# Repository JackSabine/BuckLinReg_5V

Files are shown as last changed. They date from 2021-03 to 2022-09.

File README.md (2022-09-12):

# Buck + Linear Regulator

Power supply for the Breadboard\_CPU.  This converter accepts input voltages 8 - 13 V and will output a regulated 5 V.

Finished PCB of the power supply

Tried to bodge a wire to measure a voltage without a testpoint...  Oops...

Oops

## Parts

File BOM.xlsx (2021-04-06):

MFPN | Digikey PN | Qty
156120RS75000 | 732-5030-1-ND | 2
156120VS75000 | 732-5032-1-ND | 2
156120YS75000 | 732-5034-1-ND | 2
796634-4 | A98225-ND | 2
796638-4 | A98237-ND | 2
A750EK476M1EAAE040 | 399-13665-ND | 2
BZX84C10-7-F | BZX84C10-FDICT-ND | 2
BZX84-C2V4,215 | 1727-4249-1-ND‎ (https://www.digikey.com/product-detail/en/BZX84-C2V4%2c215/1727-4249-1-ND/2122205/?itemSeq=360465044) | 2
C3216X7R1H106K160AC | 445-181601-1-ND | 4
‎CL32B106KBJNNWE‎ | 1276-3388-1-ND‎ (https://www.digikey.com/product-detail/en/CL32B106KBJNNWE/1276-3388-1-ND/3891474) | 4
CSR1206FT10L0 | CSR1206FT10L0CT-ND | 2
EG1201 | EG1901-ND | 2
GCM21BR72A104KA37L | 490-4789-1-ND | 4
GRM188R72A104KA35D | 490-3285-1-ND | 16
IHLP4040DZER6R8M8A | 541-2276-1-ND | 2
INA180A3IDBVR | 296-47654-1-ND‎ (https://www.digikey.com/product-detail/en/INA180A3IDBVR/296-47654-1-ND/8133023/?itemSeq=360296412) | 2
LM1085ISX-5.0/NOPB | 296-35391-1-ND | 2
PMBT2222 | 1727-1135-1-ND | 2
RMCF1206FT22K1 | RMCF1206FT22K1CT-ND | 2
RMCF1206FT3K60 | RMCF1206FT3K60CT-ND | 2
RMCF1206JT10K0 | RMCF1206JT10K0CT-ND | 16
RMCF1206JT12K0 | RMCF1206JT12K0CT-ND | 2
RMCF1206JT33K0 | RMCF1206JT33K0CT-ND | 2
RMCF1206JT68K0 | RMCF1206JT68K0CT-ND | 2
RMCF2010FT30R0 | RMCF2010FT30R0CT-ND | 2
SN74HCT00DR | 296-14860-1-ND | 2
SN74HCT02DR | 296-14861-1-ND | 2
SI4435FDY-T1-GE3 | SI4435FDY-T1-GE3CT-ND | 2
TCM810MENB713 | TCM810MENB713CT-ND | 2
TLV7011DBVR | 296-TLV7011DBVRCT-ND‎ (https://www.digikey.com/product-detail/en/TLV7011DBVR/296-TLV7011DBVRCT-ND/10435217/?itemSeq=360296418) | 2
TLV76050DBZT | 296-47017-1-ND | 2
TPS56339DDCR | 296-53568-1-ND | 2

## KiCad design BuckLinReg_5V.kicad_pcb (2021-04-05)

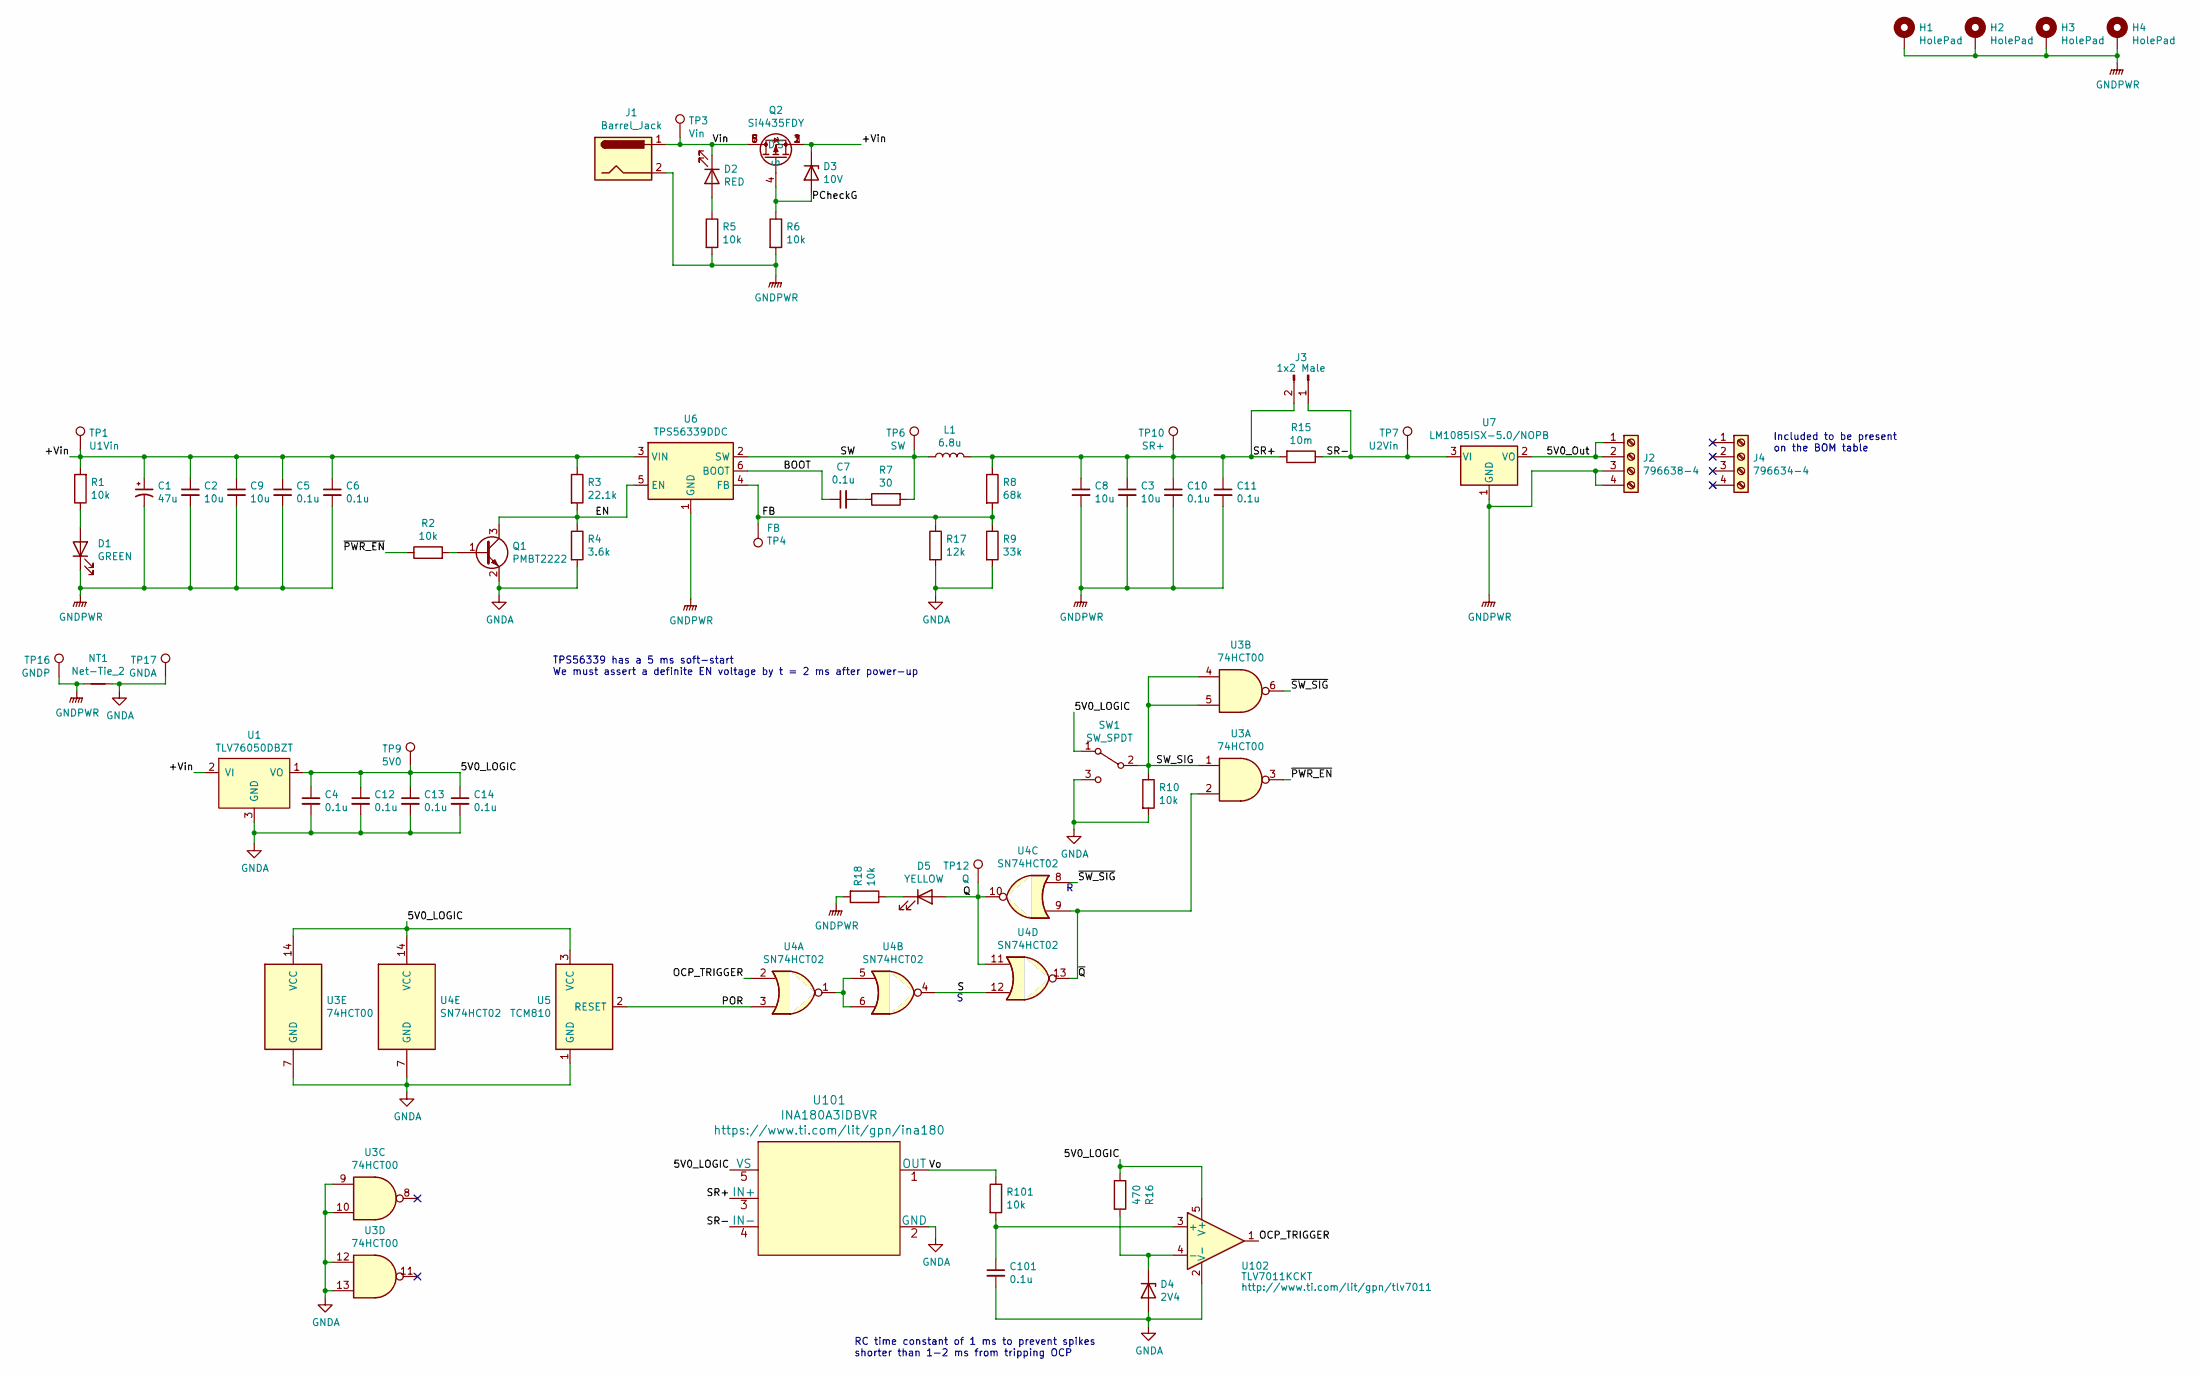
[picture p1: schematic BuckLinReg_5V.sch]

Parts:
C1: 47u; CP_Radial_D6.3mm_P2.50mm
C2, C3: 10u; C_1206_3216Metric_Pad1.33x1.80mm_HandSolder
C4, C6, C7, C11, C12, C13, C14, C101: 0.1u; C_0603_1608Metric_Pad1.08x0.95mm_HandSolder
C5, C10: 0.1u; C_0805_2012Metric_Pad1.18x1.45mm_HandSolder
C8, C9: 10u; C_1210_3225Metric_Pad1.33x2.70mm_HandSolder
D1: GREEN; D_1206_3216Metric_Pad1.42x1.75mm_HandSolder
D2: RED; D_1206_3216Metric_Pad1.42x1.75mm_HandSolder
D3: 10V; D_SOT-23_ANK
D4: 2V4; SOT-23_Handsoldering
D5: YELLOW; D_1206_3216Metric_Pad1.42x1.75mm_HandSolder
H1, H2, H3, H4: HolePad; ProjectBoxMountingHole_X001WPJR9N
J1: Barrel_Jack; BarrelJack_CUI_PJ-102AH_Horizontal
J2: 796638-4; 796636-4
J3: 1x2 Male; PinHeader_1x02_P2.54mm_Vertical
J4: 796634-4
L1: 6.8u; IHLP4040DZER6R8M8A
NT1: Net-Tie_2; NetShorter
Q1: PMBT2222; SOT-23_Handsoldering
Q2: Si4435FDY; SO-8_3.9x4.9mm_P1.27mm
R1, R2, R5, R6, R10, R18, R101: 10k; R_1206_3216Metric_Pad1.30x1.75mm_HandSolder
R3: 22.1k; R_1206_3216Metric_Pad1.30x1.75mm_HandSolder
R4: 3.6k; R_1206_3216Metric_Pad1.30x1.75mm_HandSolder
R7: 30; R_2010_5025Metric_Pad1.40x2.65mm_HandSolder
R8: 68k; R_1206_3216Metric_Pad1.30x1.75mm_HandSolder
R9: 33k; R_1206_3216Metric_Pad1.30x1.75mm_HandSolder
R15: 10m; R_1206_3216Metric_Pad1.30x1.75mm_HandSolder
R16: 470; R_1206_3216Metric_Pad1.30x1.75mm_HandSolder
R17: 12k; R_1206_3216Metric_Pad1.30x1.75mm_HandSolder
SW1: SW_SPDT; PinHeader_1x03_P2.54mm_Vertical
TP1: U1Vin; TestPoint_THTPad_D2.0mm_Drill1.0mm
TP3: Vin; TestPoint_THTPad_D2.0mm_Drill1.0mm
TP4: FB; TestPoint_THTPad_D2.0mm_Drill1.0mm
TP6: SW; TestPoint_THTPad_D2.0mm_Drill1.0mm
TP7: U2Vin; TestPoint_THTPad_D2.0mm_Drill1.0mm
TP9: 5V0; TestPoint_THTPad_D2.0mm_Drill1.0mm
TP10: SR+; TestPoint_THTPad_D2.0mm_Drill1.0mm
TP12: Q; TestPoint_THTPad_D2.0mm_Drill1.0mm
TP16: GNDP; TestPoint_THTPad_D2.0mm_Drill1.0mm
TP17: GNDA; TestPoint_THTPad_D2.0mm_Drill1.0mm
U1: TLV76050DBZT; SOT-23_Handsoldering
U3: 74HCT00; SOIC-14_3.9x8.7mm_P1.27mm
U4: SN74HCT02; SOIC-14_3.9x8.7mm_P1.27mm
U5: TCM810; SOT-23_Handsoldering
U6: TPS56339DDC; SOT-23-6
U7: LM1085ISX-5.0/NOPB; TO-263-3_TabPin2
U101: INA180A3IDBVR; SOT-23-5_HandSoldering
U102: TLV7011KCKT; SOT-23-5_HandSoldering

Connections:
/5V0_LOGIC: C4.1, C12.1, C13.1, C14.1, R16.1, SW1.1 (A), TP9.1, U1.1 (VO), U3.14 (VCC), U4.14 (VCC), U5.3 (VCC), U101.5 (VS), U102.5 (V+)
/5V0_Out: J2.1, J2.2, U7.2 (VO)
/+Vin: C1.1, C2.1, C5.1, C6.1, C9.1, D3.1 (K), Q2.1 (S), Q2.2 (S), Q2.3 (S), R1.2, R3.1, TP1.1, U1.2 (VI), U6.3 (VIN)
/BOOT: C7.1, U6.6 (BOOT)
/EN: Q1.3 (C), R3.2, R4.1, U6.5 (EN)
/FB: R8.2, R9.1, R17.1, TP4.1, U6.4 (FB)
/OCP_TRIGGER: U4.2, U102.1; also elsewhere on the board
/PCheckG: D3.2 (A), Q2.4 (G), R6.1
/POR: U4.3, U5.2 (RESET)
/Q: D5.2 (A), TP12.1, U4.10, U4.11
/S: U4.4, U4.12
/SR+: C3.1, C8.1, C10.1, C11.1, J3.2, L1.2, R8.1, R15.2, TP10.1, U101.3 (IN+)
/SR-: J3.1, R15.1, TP7.1, U7.3 (VI), U101.4 (IN-)
/SW: L1.1, R7.2, TP6.1, U6.2 (SW)
/SW_SIG: R10.1, SW1.2 (B), U3.1, U3.4, U3.5
/Vin: D2.1 (K), J1.1, Q2.5 (D), Q2.6 (D), Q2.7 (D), Q2.8 (D), TP3.1
/Vo: R101.1, U101.1 (OUT); also elsewhere on the board
/~PWR_EN: R2.1, U3.3
/~Q: U3.2, U4.9, U4.13
/~SW_SIG: U3.6, U4.8
GNDA: C4.2, C12.2, C13.2, C14.2, C101.2, D4.2 (A), NT1.2, Q1.2 (E), R4.2, R9.2, R10.2, R17.2, SW1.3 (C), TP17.1, U1.3 (GND), U3.7 (GND), U3.9, U3.10, U3.12, U3.13, U4.7 (GND), U5.1 (GND), U101.2 (GND), U102.2 (V-)
GNDPWR: C1.2, C2.2, C3.2, C5.2, C6.2, C8.2, C9.2, C10.2, C11.2, D1.1 (K), H1.1, H2.1, H3.1, H4.1, J1.2, J2.3, J2.4, NT1.1, R5.2, R6.2, R18.2, TP16.1, U6.1 (GND), U7.1 (GND)
unnamed: C7.2, R7.1
unnamed: C101.1, R101.2, U102.3 (+)
unnamed: D1.2 (A), R1.1
unnamed: D2.2 (A), R5.1
unnamed: D4.1 (K), R16.2, U102.4 (-)
unnamed: D5.1 (K), R18.1
unnamed: Q1.1 (B), R2.2
unnamed: U4.1, U4.5, U4.6

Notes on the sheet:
TPS56339 has a 5 ms soft-start We must assert a definite EN voltage by t = 2 ms after power-up
Included to be present on the BOM table
RC time constant of 1 ms to prevent spikes shorter than 1-2 ms from tripping OCP

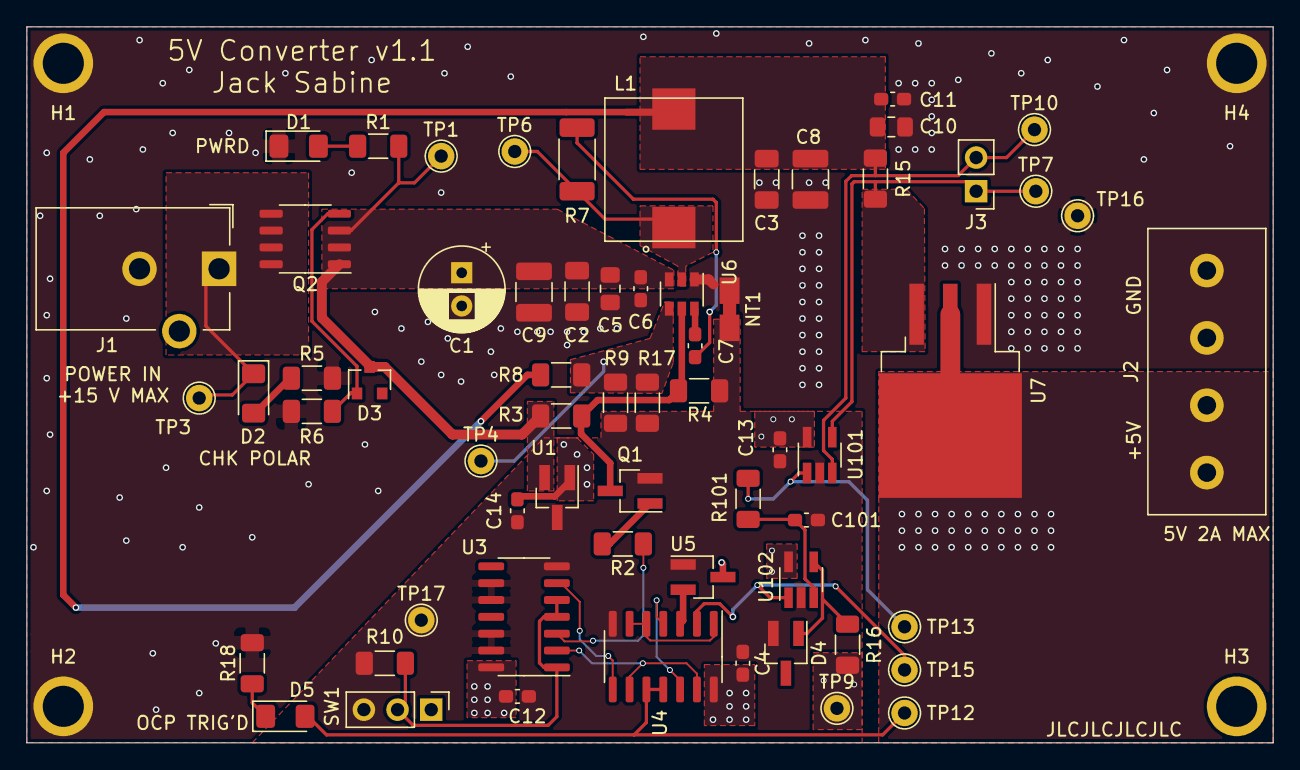
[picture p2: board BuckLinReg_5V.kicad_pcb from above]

Board: 2 copper layers, 94.0 x 54.0 mm, 67 parts (0 on the bottom side), 30 nets.

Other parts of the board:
TP13: Iout; TestPoint_THTPad_D2.0mm_Drill1.0mm
TP15: OCPT; TestPoint_THTPad_D2.0mm_Drill1.0mm

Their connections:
/OCP_TRIGGER: TP15.1; also elsewhere on the board
/Vo: TP13.1; also elsewhere on the board

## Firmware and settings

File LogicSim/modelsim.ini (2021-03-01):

; Copyright 1991-2017 Mentor Graphics Corporation
;
; All Rights Reserved.
;
; THIS WORK CONTAINS TRADE SECRET AND PROPRIETARY INFORMATION WHICH IS THE PROPERTY OF 
; MENTOR GRAPHICS CORPORATION OR ITS LICENSORS AND IS SUBJECT TO LICENSE TERMS.
;   

[Library]
others = $MODEL_TECH/../modelsim.ini
;
; VITAL concerns:
;
; The library ieee contains (among other packages) the packages of the
; VITAL 2000 standard.  When a design uses VITAL 2000 exclusively, it should use
; the physical library ieee (recommended), or use the physical library
; vital2000, but not both.  The design can use logical library ieee and/or
; vital2000 as long as each of these maps to the same physical library, either
; ieee or vital2000.
;
; A design using the 1995 version of the VITAL packages, whether or not
; it also uses the 2000 version of the VITAL packages, must have logical library
; name ieee mapped to physical library vital1995.  (A design cannot use library
; vital1995 directly because some packages in this library use logical name ieee
; when referring to the other packages in the library.)  The design source
; should use logical name ieee when referring to any packages there except the
; VITAL 2000 packages.  Any VITAL 2000 present in the design must use logical
; name vital2000 (mapped to physical library vital2000) to refer to those
; packages.
; ieee = $MODEL_TECH/../vital1995
;
; For compatiblity with previous releases, logical library name vital2000 maps
; to library vital2000 (a different library than library ieee, containing the
; same packages).
; A design should not reference VITAL from both the ieee library and the
; vital2000 library because the vital packages are effectively different.
; A design that references both the ieee and vital2000 libraries must have
; both logical names ieee and vital2000 mapped to the same library, either of
; these:
;   $MODEL_TECH/../ieee
;   $MODEL_TECH/../vital2000
;

; Altera Primitive libraries
;
; VHDL Section
;
;
; Verilog Section
;

work = C:/Users/jack/OneDrive/Documents/GitHub/BuckLinReg_5V/LogicSim/sim/temp/workingDir
[vcom]
; VHDL93 variable selects language version as the default. 
; Default is VHDL-2002.
; Value of 0 or 1987 for VHDL-1987.
; Value of 1 or 1993 for VHDL-1993.
; Default or value of 2 or 2002 for VHDL-2002.
; Value of 3 or 2008 for VHDL-2008
VHDL93 = 2002

; Show source line containing error. Default is off.
; Show_source = 1

; Turn off unbound-component warnings. Default is on.
; Show_Warning1 = 0

; Turn off process-without-a-wait-statement warnings. Default is on.
; Show_Warning2 = 0

; Turn off null-range warnings. Default is on.
; Show_Warning3 = 0

; Turn off no-space-in-time-literal warnings. Default is on.
; Show_Warning4 = 0

; Turn off multiple-drivers-on-unresolved-signal warnings. Default is on.
; Show_Warning5 = 0

; Turn off optimization for IEEE std_logic_1164 package. Default is on.
; Optimize_1164 = 0

; Turn on resolving of ambiguous function overloading in favor of the
; "explicit" function declaration (not the one automatically created by
; the compiler for each type declaration). Default is off.
; The .ini file has Explicit enabled so that std_logic_signed/unsigned
; will match the behavior of synthesis tools.
Explicit = 1

; Turn off acceleration of the VITAL packages. Default is to accelerate.
; NoVital = 1

; Turn off VITAL compliance checking. Default is checking on.
; NoVitalCheck = 1

; Ignore VITAL compliance checking errors. Default is to not ignore.
; IgnoreVitalErrors = 1

; Turn off VITAL compliance checking warnings. Default is to show warnings.
; Show_VitalChecksWarnings = 0

; Keep silent about case statement static warnings.
; Default is to give a warning.
; NoCaseStaticError = 1

; Keep silent about warnings caused by aggregates that are not locally static.
; Default is to give a warning.
; NoOthersStaticError = 1

; Treat as errors:
;   case statement static warnings
;   warnings caused by aggregates that are not locally static
; Overrides NoCaseStaticError, NoOthersStaticError settings.
; PedanticErrors = 1

; Turn off inclusion of debugging info within design units.
; Default is to include debugging info.
; NoDebug = 1

; Turn off "Loading..." messages. Default is messages on.
; Quiet = 1

; Turn on some limited synthesis rule compliance checking. Checks only:
;    -- signals used (read) by a process must be in the sensitivity list
; CheckSynthesis = 1

; Activate optimizations on expressions that do not involve signals,
; waits, or function/procedure/task invocations. Default is off.
; ScalarOpts = 1

; Turns on lint-style checking.
; Show_Lint = 1

; Require the user to specify a configuration for all bindings,
; and do not generate a compile time default binding for the
; component. This will result in an elaboration error of
; 'component not bound' if the user fails to do so. Avoids the rare
; issue of a false dependency upon the unused default binding.
; RequireConfigForAllDefaultBinding = 1
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

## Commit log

2021-02-06 Created .sch, selected parts, started PCB layout
    [BuckLinReg_5V.kicad_pcb, BuckLinReg_5V.sch]
2021-02-11 Added overcurrent protection circuit and assigned all MFPNs and footprints
    [BuckLinReg_5V.kicad_pcb, BuckLinReg_5V.sch]
2021-02-13 Two grounds: GNDA and pwrGND. Continued PCB dev.
    [BuckLinReg_5V.kicad_pcb, BuckLinReg_5V.sch]
2021-02-22 Simulated zener for different values R. Routed logic portion of board.
    [BuckLinReg_5V.kicad_pcb, BuckLinReg_5V.sch]
2021-02-23 Added testpoints and finished routing board
    [BuckLinReg_5V.kicad_pcb, BuckLinReg_5V.sch]
2021-02-26 Converted to 4-layer PCB. Minimum track width 0.25 mm.
    [BuckLinReg_5V.kicad_pcb]
2021-02-26 Redid vias and fixed silkscreen overlap
    [BuckLinReg_5V.kicad_pcb]
2021-02-27 Added new power barrier connector. Increased minimum copper to copper clearance to 0.21 mm.
    [BuckLinReg_5V.kicad_pcb, BuckLinReg_5V.sch]
2021-02-27 Moved some test points to allow for better ground high current return path
    [BuckLinReg_5V.kicad_pcb]
2021-03-01 Verified OCP switch logic in verilog
2021-03-22 PCB Ordered
    [BOM.xlsx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]
2021-04-03 Begin rev. 2 sch and PCB resize to 94x54mm
    [BuckLinReg_5V.kicad_pcb, BuckLinReg_5V.sch]
2021-04-03 Completed initial layout of rev. 2
    [BuckLinReg_5V.kicad_pcb, BuckLinReg_5V.sch]
2021-04-05 Changed nettie and gnd clearances
    [BuckLinReg_5V-B_Cu.gbr, BuckLinReg_5V-B_Mask.gbr, BuckLinReg_5V-B_SilkS.gbr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]
2021-04-06 PCB v1.1 ordered
    [BOM.xlsx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]
2021-12-08 Prettifying schematic
    [BuckLinReg_5V.sch]

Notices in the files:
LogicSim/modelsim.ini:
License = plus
